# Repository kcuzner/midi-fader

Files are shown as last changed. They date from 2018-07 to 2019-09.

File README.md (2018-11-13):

# Simple MIDI Fader

By Kevin Cuzner

## Project Status

 * PCB complete and working (with an additional load added to reduce regulator noise)
 * Firmware feature-complete and mostly working
   * Emulates as HID and USB-MIDI devices
   * Not tested on Windows yet
 * Case OpenSCAD in progress
 * Configuration host software in progress

## Featureset

 * Two 60mm analog fader inputs
 * USB Audio Class interface, aiming for driverless on Windows 7 and 10
 * Driverless HID interface for configuration
   * It might be trivially simple to echo the fader status in the HID reports...

## Main Component Options

 * Faders (note that they have different footprints and different levers):
   * Expensive faders ($4.74, very light movement force): PTB6053-2010APB103-ND
   * Cheap faders ($1.73): PTA6043-2015CPB103-ND
 * Microcontrollers:
   * 497-17354-1-ND: STM32F070F6P6, $1.48, 32K flash, 6K RAM, 20-TSSOP.
     * No CRS, external XTAL required.
   * 497-15099-ND: STM32F070CBT6, $2.52, 128K flash, 16K RAM, 48-LQFP
     * No CRS, exteranl XTAL required.
   * 497-17344-ND: STM32042F6P6, $2.25, 32K flash, 6K RAM, 20-TSSOP.
     * Has a CRS
     * 24.6mA with all peripherals and HSI48 enabled
 * 609-4052-1-ND: Micro-USB, $0.76
 * 455-1790-1-ND: JST-SH header for programming, $0.63
 * Power supply solution:
   * MCP1603T-330I/OSCT-ND: Cheap buck regulator, but not too cheap. $1.01,
     TSOT-23
     * Noise issues at low currents (leaves PWM mode and skips pulses).
   * 576-4764-1-ND: MIC5504 buck regulator, $0.11, SOT23-5.
     * At a 100mA load, the case will heat 42.6C. Not over the top, but really
       quite hot.
     * We could do this AND the buck regulator, but just have this for the
       analog.

## Notes

### Notes about the logical MIDI protocol

 * MIDI has two types of bytes STATUS and DATA.
 * A STATUS byte has its MSB set
 * A DATA byte has its MSB cleared (hence why there are only ever 0 to 127 data
   values)
 * Usually, the lower nybble of the STATUS byte is a channel number (there are
   16 channels).
 * The number of data bytes to follow varies by which STATUS byte preceded them.
 * Interesting STATUS commands (upper nybble shown) for this project:
   * 0xB: Control Change. Followed by a controller number (1 data byte) and a
     controller value (1 data byte). Although there are possibly 127 controller
     numbers, numbers 120-127 are reserved for "Channel Mode Messages". Several
     of these are commonly used.
   * 0xE: Pitch Bend. Followed by two DATA bytes encoding a 14-bit value, LSB
     first. 0x2000 is center.
 * https://www.cs.cmu.edu/~music/cmsip/readings/MIDI%20tutorial%20for%20programmers.html
 * https://www.midi.org/specifications-old/item/table-1-summary-of-midi-message

### Notes about USB and MIDI

 * Windows XP and above seem to support USB MIDI except Elements.
   * "Elements" are things that process MIDI
   * "Jacks" are supported, and they are exactly what they sound like. This will
     implement a Jack.
   * Elements and Jacks are "Entities"
 * http://www.usb.org/developers/docs/devclass_docs/midi10.pdf

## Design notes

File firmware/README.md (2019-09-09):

# USB Midi-Fader Firmware

This is the firmware for the USB Midi-Fader. It runs on an STM32F042X6
microcontroller and has the following features:

- Enumerates as a USB Human Interface Device
- Enumerates as a USB Audio Device
- Reads up to 8 attached shift registers for button inputs
  - Detects how many shift registers are attached
- Writes up to 8 attached shift registers for LED outputs
- Reads up to 8 analog inputs
- Completely configurable in terms of what it sends
  - Emulates a Mackie control

## Building

### Build Prerequisites

These are names of Arch Linux packages.

- `arm-none-eabi-gcc`
- `arm-none-eabi-binutils`
- `arm-none-eabi-newlib`
- `python` (Python 3)
- `openocd`

### Build process

```
$ make
```

### Install process

This process will erase the device, flash the bootloader, then use a python
script to update the flash to contain the firmware binary.

```
$ make install
```

#### Installing the bootloader only

This erases the device and installs the bootloader, but stops short of
installing the firmware image. It does, however, require that the firmware can
be built since it uses the `storage` segment of the firmware.

```
$ make flash
```

### Update process

```
$ make update
```

### Debugging

```
$ make gdb
```

### Cleanup

An openocd server is started in the background whenever a flashing or debugging
operation is performed. To stop the server run:

```
$ make stop
```

This step is performed automatically when running `make clean`

## What can be configured

Generally:

- Event rate (`0x80000001`)

For each button:

- Channel (`0x4000NN01, NN = button number`)
- "On" value (`0x4000NN02`)
- "Off" value (`0x4000NN03`)
- Mode: Control or Note (`0x4000NN04`)
- Control number (`0x4000NN05`)
- Note number (`0x4000NN06`)

For each fader

- Channel (`0x2000NN01`, NN = fader number)
- Mode: Control or Pitch Bend (`0x2000NN02`)
- Control number (`0x2000NN03`)
- Control minimum (`0x2000NN04`)
- Control maximum (`0x2000NN05`)
- Pitch minimum (`0x2000NN06`)
- Pitch maximum (`0x2000NN07`)

Other read-only parameters:

- Number of faders/buttons: (`0x80000002`)

### Configuration Protocol

Configuration is accomplished through the HID interface, rather than directly
through MIDI (but maybe this will come later). The communication is arranged
through the two 64-byte IN and OUT reports.

In general, the reports have the following format:

```
Bytes 0-3: Command number
Bytes 4-7: Parameter 0
Bytes 8-11: Parameter 1
...
```

Words should be packed LSB first.

An IN report will contain the command number of the command it is responding to.
Parameters can be IN, OUT, or both. The parameters will be echoed in the
corresponding OUT report.

#### Status

The Status command has the following format:

 - Command: 0x00
 - Parameter 0 (IN): Constant 0xDEADBEEF
 - Parameter 1 (IN): Number of channels
 - Remaining parameters (IN): Null terminated git version string of the firmware

#### Set Parameter

The Set Parameter command has the following format:

 - Command: 0x80
 - Parameter 0 (IN): Status (0 = success, error code otherwise)
 - Parameter 1 (OUT): Parameter number
 - Parameter 2 (OUT): Parameter value
 - Parameter 3 (OUT): Parameter size in bytes

#### Get Parameter

The Get Parameter command has the following format:

 - Command: 0x40
 - Parameter 0 (IN): Status (0 = success, error code otherwise)
 - Parameter 1 (OUT): Parameter number
 - Parameter 2 (IN): Parameter value
 - Parameter 3 (IN): Parameter size in bytes

#### Enter Bootloader

The Enter Bootloader command has the following format:

 - Command: 0x0C
 - Parameters: Ignored

The device will immediately disconnect and re-enumerate as the bootloader device
upon receiving this command.

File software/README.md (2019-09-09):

# Software

The software for the midi fader is designed to be cross platform between Windows and Linux. With this in mind, it is
written in [Rust][1] and uses [imgui][2] for the user interface. There were many hiccups during development and it took
far far longer to write this than the entire PCB design and firmware development process. Most of this can be attributed
to my inexperience with Rust.

## Design Choices

### GUI

 - imgui is statically compiled into the application. This removes any dependency on external dynamically linked
   libraries.
 - Of the rather limited GUI options in Rust, I felt that imgui was the most developed since it mirrors the C API almost
   exactly.
 - The standard practice of having a special thread for GUI activity is followed, even though imgui is stateless.

### Device Communication

[1]: https://rust-lang.org
[2]: https://github.com/ocornut/imgui

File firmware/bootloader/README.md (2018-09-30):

# USB-Midi Fader Bootloader

The bootloader provides a mechanism for reprogramming the system without using
SWD beyond the first initial flashing of this image.

## Build instructions

**Prerequisites:**

 - arm-none-eabi-gcc
 - arm-none-eabi-binutils
 - python3

**To build:**

 1. Run `make` in this directory.

**To install or debug:**

Invoking `make` in this directory does not allow for actually flashing the
device. Since the application which uses this bootloader has its very own
"storage" segment, independent from the one generated here (which only contains
a very small subset of the parameters in storage), all flashing and debugging
should take place in the parent directory.

## Program Format

This bootloader lives in the first 8KB of program flash and reserves the first
256 bytes of RAM. Programs to be loaded through this bootloader must have their
sections located in the following format:

```
Flash:
0x08002000: User program (.text, .rodata, etc)

RAM:
0x20000100: User data until the end of memory

Information block:
All sections may be used by the program
```

All writes and reads to the bootloader section (0x08000000-0x08001FFF,
0x08080000-0x080800FF) will be ignored and generate an appropriate status
report.

Firmware which writes to the first 256 bytes of RAM may cause the bootloader
to behave unexpectedly.

## Programming Verification

The bootloader includes automatic program verification as the device is
programmed in half-pages. However, it is still recommended to read back the
entire user section of program memory to verify that all blocks have been
written.

As an additional countermeasure against incorrect programming, once the device
enters bootloader mode, it will always enter bootloader mode on reset until
the "Exit Bootloader Mode" command is received. This prevents errors stemming
from device resets or loss of power during the programming process by allowing
the host software to start over programming without needing to resort to an
external reset.

## Protocol

### Entering Bootloader Mode

Bootloader is entered by simply performing any reset except a power-on reset.
If the power-on reset bit is set, the bootloader clears it and then jumps to the
user program, if it has been programmed.

### USB

The bootloader will appear as a USB device using the shared libusb VID/PID and
the name "LED Wristwatch Bootloader". It enumerates as an HID device and will
send and receive 64-byte reports. Each report encapsulates a command. As the
device is stateful, multiple host programs accessing the device at once may
cause corruption. The IN and OUT reports both utilize the default HID report ID,
so no HID report ID needs to be sent with the report.

The device will generate 64-byte IN reports on occasion to communicate the
device status. These reports have the following format:

```
Byte 0-3: First four bytes of the last command received or 0x00000000
Byte 4-7: Status flags
Byte 8-11: CRC32 of the lower page report to follow or just processed, if applicable
Byte 12-15: CRC32 of the upper page report to follow or just processed, if applicable
Byte 16-63: N/A
```

For an interpretation of the status flags, please see the `BootloaderError` enum
defined in `src/bootloader.c`. In general, these flags will only be set on
error and a `0` in the flags value can be interpreted as command success.

### CRC32 Implementation

The CRC32 is implemented using the hardware on the STM32. The host software will
use the `zlib` implementation of CRC32.

### Resetting the programming state machine

When the host program starts, a state machine reset command should be sent to
ensure the device is in a known state before performing any programming
commands. The reset command consists of sending the following report three
times:

The reset command has the following format:

```
Byte 0-63: 0x00
```

Upon receipt of the command, the device will generate a status report

### Exiting Bootloader Mode Before Programming

If the bootloader was started, but no programming operations have occurred and
the device was previously programmed, the user program can be started by issuing
the following command:

```
Byte 0: 0x3E
Byte 1-3: 0x00
Byte 4-63: N/A
```

Upon receipt of this command, the device will immediately reset and enter the
user program, if one has already been programmed and no new programming commands
have been received. Otherwise, a status report will be generated with an
appropriate error flag.

### Erasing the Flash

The STM32F0xx erases by 1KB page. Prior to programming the flash, an erase
command should be sent for each page:

```
Byte 0: 0x88
Byte 1-3: 0x00
Byte 4: Destination address bits 7-0 (bits 6-0 are ignored)
Byte 5: Destination address bits 15-8
Byte 6: Destination address bits 23-16
Byte 7: Destination address bits 31-24
Byte 8-63: N/A
```

Upon receipt of this command, the device will erase the 1KB page that the passed
address lies within and issue a status report.

### Programming the Flash

Programming the flash requires 3 reports to be sent: A write command and
two half-page OUT reports.

The write command has the following format:

```
Byte 0: 0x80
Byte 1-3: 0x00
Byte 4: Destination address bits 7-0 (bits 6-0 are ignored)
Byte 5: Destination address bits 15-8
Byte 6: Destination address bits 23-16
Byte 7: Destination address bits 31-24
Byte 8-11: CRC32 of the 16 32-bit words from the lower page command to follow, LSB first
Byte 12-15: CRC32 of the 16 32-bit words from the upper page command to follow, LSB first
Byte 16-63: N/A
```

Upon receipt of this command, the device will enter programming mode verify the
address that is to be written along with the erase state. The page must have
been previously erased.

The half-page command has the following format:

```
Byte 0-63: 16 32-bit words to program
```

Upon receipt of this command, the device will proceed to program the 16 words
starting at the destination address. In the event that less than a page needs
to be written, the remaining bytes should be filled with 0x00. When programming
has been completed, a status report will be generated and the device is ready to
receive the next page. Upon receipt of the final, upper page command, another
status report is generated and the device returns to the reset state.

Status commands during the programming phase will contain either a valid CRC32
for any section programmed, or zeros if the section has not been programmed. If
any error flags are set, then the device has returned to the reset state.

### Reading the Flash

Reading the flash requires 1 report to be sent and another to be received:
A read command and the page IN report.

The read command has the following format:

```
Byte 0: 0x40
Byte 1-3: 0x00
Byte 4: Source address bits 7-0 (bits 6-0 are ignored)
Byte 5: Source address bits 15-8
Byte 6: Source address bits 23-16
Byte 7: Source address bits 31-24
Byte 8-63: N/A
```

Upon receipt of this command, the device will generate two IN reports containing
the contents of the page. A status report will immediately follow and the device
returns to the reset state, being ready to accept the next command.

### Exiting Bootloader Mode After Programming

To exit bootloader mode, a report with the following format should be sent:

```
Byte 0: 0xC3
Byte 1-3: 0x00
Byte 4-7: VTOR value for the user program
Byte 8-63: N/A
```

The VTOR value should be the address at which the user program's interrupt
vector table resides. The first two words of the table are used to derive the
initial stack pointer and the location to jump to in order to initiate the user
program (reset vector).

Upon receipt of this command, the device will write the VTOR value to persistent
EEPROM and reset the device. If the VTOR value passed is invalid, or the device
is unable to write its EEPROM, it will send a status report detailing the
failure. Otherwise, it will initiate a device soft reset and the user program
will start on every power-on or low-power reset thereafter.

**This command must not be sent until the entire program has been written to
the flash.** In the event that the device stops programming before receiving
this command, it will automatically enter bootloader mode at the next reset
until it receives this command.

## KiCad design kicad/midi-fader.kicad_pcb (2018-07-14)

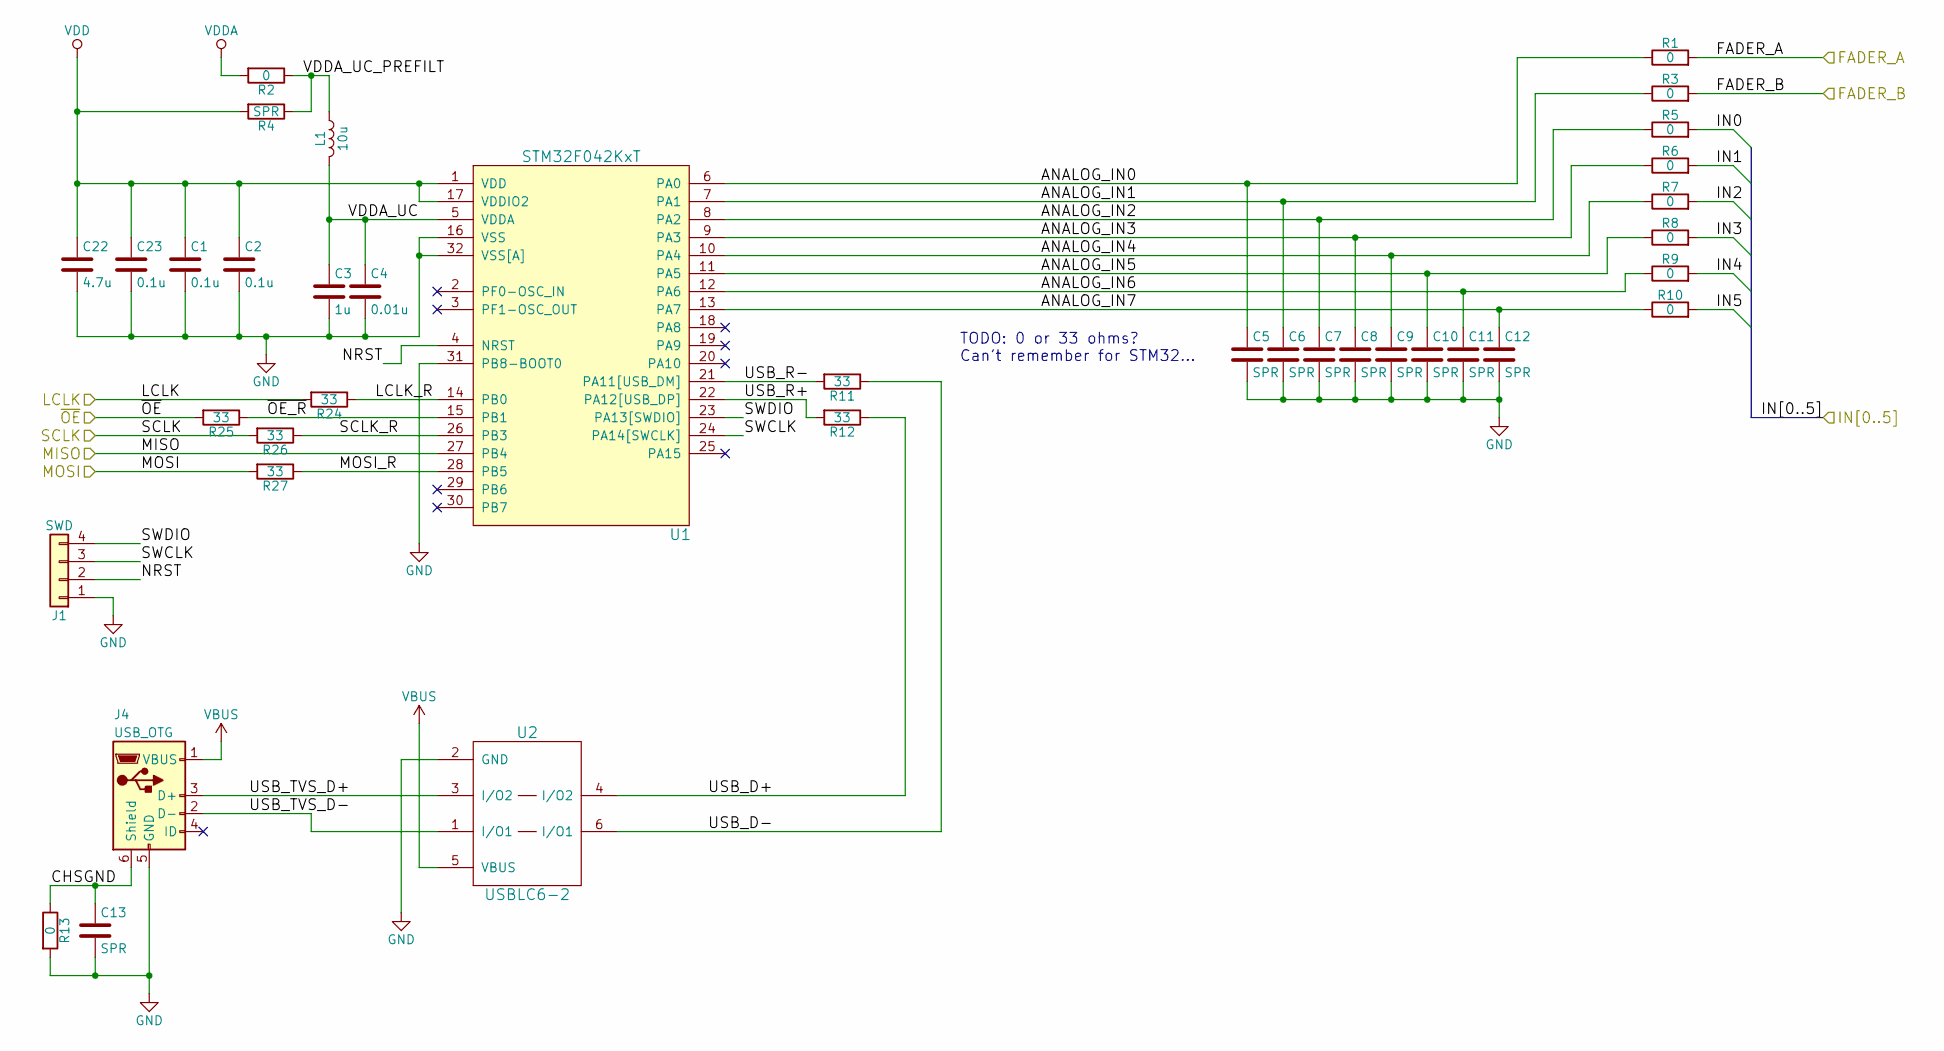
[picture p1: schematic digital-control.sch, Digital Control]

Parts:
C1, C2, C23: 0.1u; C_0402; Part No. 1276-1043-1-ND
C3: 1u; C_0603; Part No. 1276-1182-1-ND
C4: 0.01u; C_0402; Part No. 399-1038-1-ND
C5, C6, C7, C8, C9, C10, C11, C12, C13: SPR; C_0402
C22: 4.7u; C_0805; Part No. 1276-6464-1-ND
J1: SWD; JST-SH-4; Part No. 455-1790-1-ND
J4: USB_OTG; AMP-10104110-USB; Part No. 609-4052-1-ND
L1: 10u; R_0805; Part No. 587-2045-1-ND
R1, R2, R3, R5, R6, R7, R8, R9, R10, R13: 0; R_0402
R4: SPR; R_0402
R11, R12, R24, R25, R26, R27: 33; R_0402
U1: STM32F042KxT; LQFP-32_7x7mm_Pitch0.8mm; Part No. 497-14647-ND
U2: USBLC6-2; SOT-666; Part No. 497-5026-1-ND

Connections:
/Digital Control/ANALOG_IN0: C5.1, R1.1, U1.6 (PA0)
/Digital Control/ANALOG_IN1: C6.1, R3.1, U1.7 (PA1)
/Digital Control/ANALOG_IN2: C7.1, R5.1, U1.8 (PA2)
/Digital Control/ANALOG_IN3: C8.1, R6.1, U1.9 (PA3)
/Digital Control/ANALOG_IN4: C9.1, R7.1, U1.10 (PA4)
/Digital Control/ANALOG_IN5: C10.1, R8.1, U1.11 (PA5)
/Digital Control/ANALOG_IN6: C11.1, R9.1, U1.12 (PA6)
/Digital Control/ANALOG_IN7: C12.1, R10.1, U1.13 (PA7)
/Digital Control/CHSGND: C13.1, J4.6 (Shield), R13.1
/Digital Control/FADER_A: R1.2; also elsewhere on the board
/Digital Control/FADER_B: R3.2; also elsewhere on the board
/Digital Control/IN0: R5.2; also elsewhere on the board
/Digital Control/IN1: R6.2; also elsewhere on the board
/Digital Control/IN2: R7.2; also elsewhere on the board
/Digital Control/IN3: R8.2; also elsewhere on the board
/Digital Control/IN4: R9.2; also elsewhere on the board
/Digital Control/IN5: R10.2; also elsewhere on the board
/Digital Control/LCLK: R24.2; also elsewhere on the board
/Digital Control/LCLK_R: R24.1, U1.14 (PB0)
/Digital Control/MISO: U1.27 (PB4); also elsewhere on the board
/Digital Control/MOSI: R27.2; also elsewhere on the board
/Digital Control/MOSI_R: R27.1, U1.28 (PB5)
/Digital Control/NRST: J1.2, U1.4 (NRST)
/Digital Control/SCLK: R26.2; also elsewhere on the board
/Digital Control/SCLK_R: R26.1, U1.26 (PB3)
/Digital Control/SWCLK: J1.3, U1.24 (PA14[SWCLK])
/Digital Control/SWDIO: J1.4, U1.23 (PA13[SWDIO])
/Digital Control/USB_D+: R12.1, U2.4 (I/O2)
/Digital Control/USB_D-: R11.1, U2.6 (I/O1)
/Digital Control/USB_R+: R12.2, U1.22 (PA12[USB_DP])
/Digital Control/USB_R-: R11.2, U1.21 (PA11[USB_DM])
/Digital Control/USB_TVS_D+: J4.3 (D+), U2.3 (I/O2)
/Digital Control/USB_TVS_D-: J4.2 (D-), U2.1 (I/O1)
/Digital Control/VDDA_UC: C3.1, C4.1, L1.2, U1.5 (VDDA)
/Digital Control/VDDA_UC_PREFILT: L1.1, R2.1, R4.1
/Digital Control/~OE: R25.2; also elsewhere on the board
/Digital Control/~OE_R: R25.1, U1.15 (PB1)
GND: C1.2, C2.2, C3.2, C4.2, C5.2, C6.2, C7.2, C8.2, C9.2, C10.2, C11.2, C12.2, C13.2, C22.2, C23.2, J1.1, J4.5 (GND), R13.2, U1.16 (VSS), U1.31 (PB8-BOOT0), U1.32 (VSS[A]), U2.2 (GND); also elsewhere on the board
VBUS: J4.1 (VBUS), U2.5 (VBUS); also elsewhere on the board
VDD: C1.1, C2.1, C22.1, C23.1, R4.2, U1.1 (VDD), U1.17 (VDDIO2); also elsewhere on the board
VDDA: R2.2; also elsewhere on the board

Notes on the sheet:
TODO: 0 or 33 ohms? Can't remember for STM32...

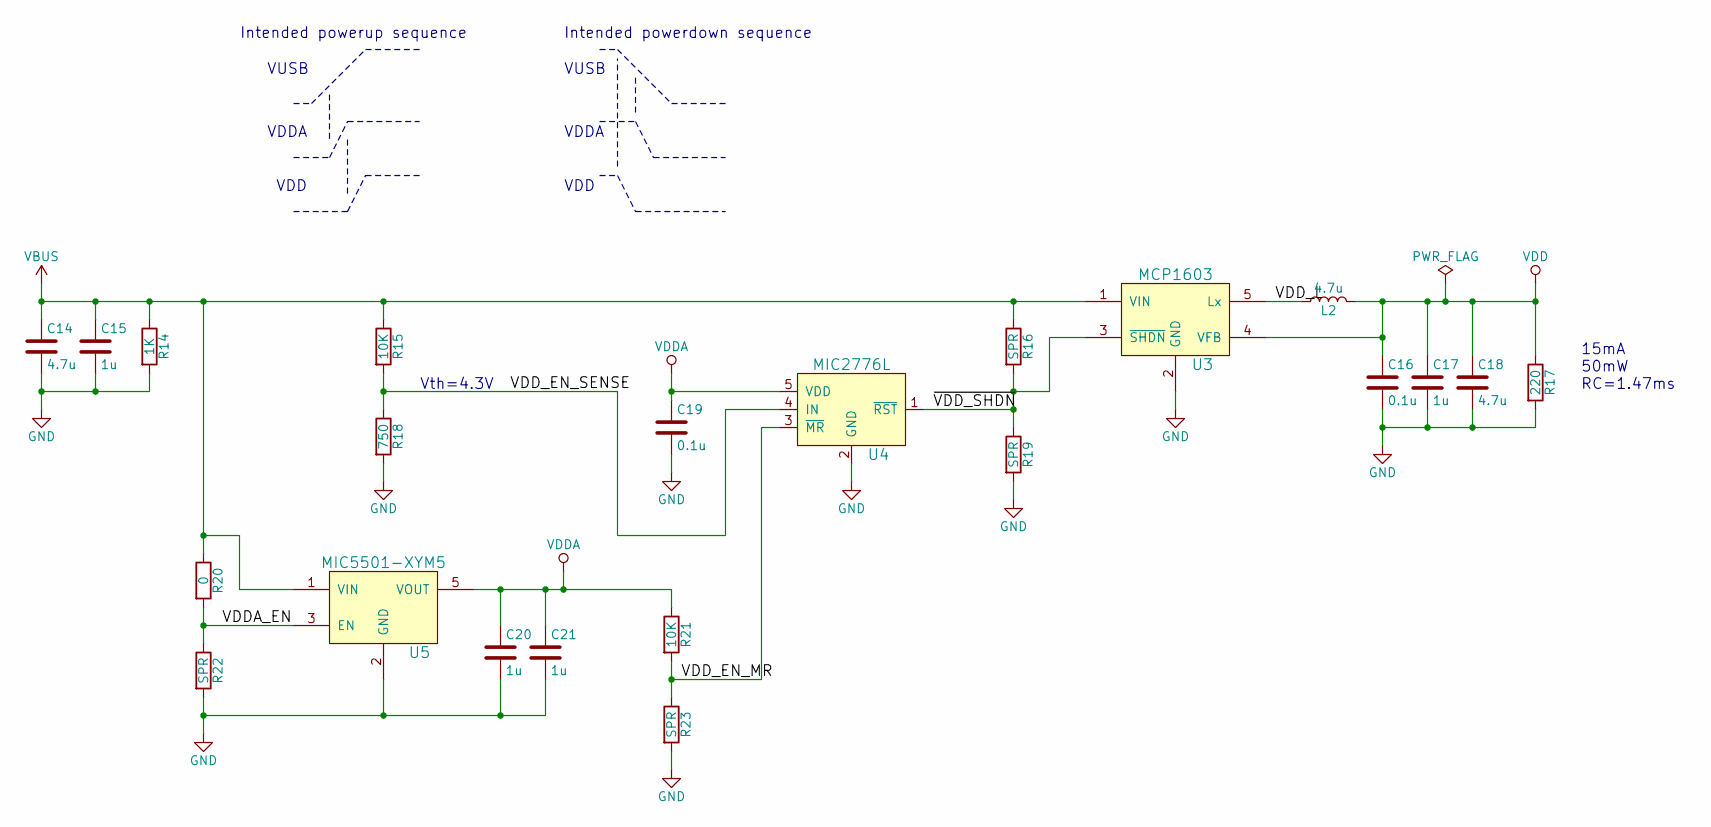
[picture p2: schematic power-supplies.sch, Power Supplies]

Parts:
C14, C18: 4.7u; C_0805; Part No. 1276-6464-1-ND
C15, C17, C20, C21: 1u; C_0603; Part No. 1276-1182-1-ND
C16, C19: 0.1u; C_0402; Part No. 1276-1043-1-ND
L2: 4.7u; Wurth_TPC_3816; Part No. 732-1008-1-ND
R14: 1K; R_0805
R15, R21: 10K; R_0402
R16, R19, R22, R23: SPR; R_0402
R17: 220; R_1206
R18: 750; R_0402
R20: 0; R_0402
U3: MCP1603; TSOT-23-5; Part No. MCP1603T-330I/OSCT-ND
U4: MIC2776L; SOT-23-5; Part No. 576-2686-1-ND
U5: MIC5501-XYM5; SOT-23-5; Part No. 576-4764-1-ND

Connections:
/Power Supplies/VDDA_EN: R20.2, R22.1, U5.3 (EN)
/Power Supplies/VDD_EN_MR: R21.2, R23.1, U4.3 (~MR)
/Power Supplies/VDD_EN_SENSE: R15.2, R18.1, U4.4 (IN)
/Power Supplies/VDD_L: L2.1, U3.5 (Lx)
/Power Supplies/~VDD_SHDN: R16.2, R19.1, U3.3 (~SHDN), U4.1 (~RST)
GND: C14.2, C15.2, C16.2, C17.2, C18.2, C19.2, C20.2, C21.2, R14.2, R17.2, R18.2, R19.2, R22.2, R23.2, U3.2 (GND), U4.2 (GND), U5.2 (GND); also elsewhere on the board
VBUS: C14.1, C15.1, R14.1, R15.1, R16.1, R20.1, U3.1 (VIN), U5.1 (VIN); also elsewhere on the board
VDD: C16.1, C17.1, C18.1, L2.2, R17.1, U3.4 (VFB); also elsewhere on the board
VDDA: C19.1, C20.1, C21.1, R21.1, U4.5 (VDD), U5.5 (VOUT); also elsewhere on the board

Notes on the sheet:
Intended powerup sequence
VUSB
VDDA
VDD
Intended powerdown sequence
15mA 50mW RC=1.47ms
Vth=4.3V

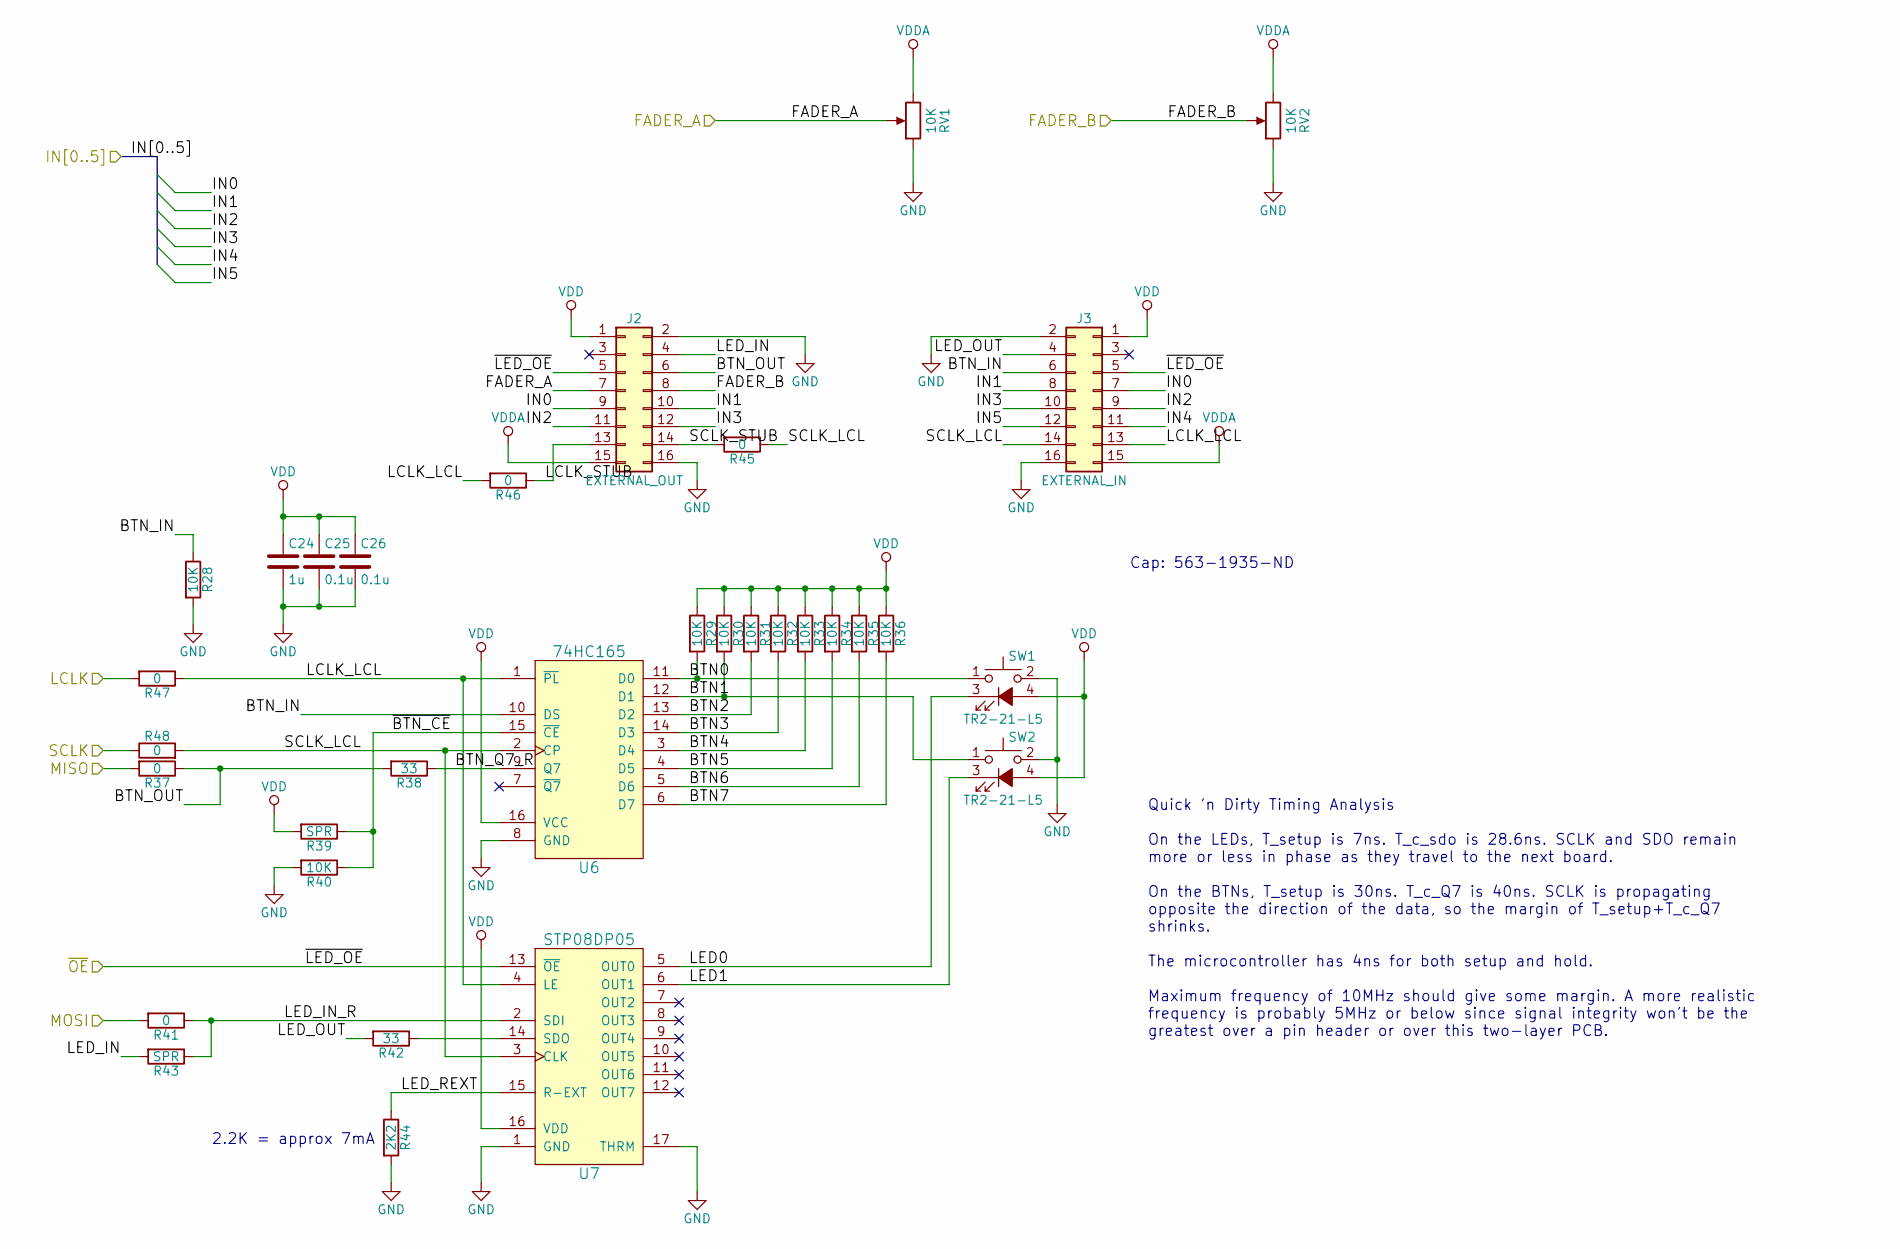
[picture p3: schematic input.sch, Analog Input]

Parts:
C24: 1u; C_0603; Part No. 1276-1182-1-ND
C25, C26: 0.1u; C_0402; Part No. 1276-1043-1-ND
J2: EXTERNAL_OUT; Pin_Header_Angled_2x08_Pitch2.54mm; Part No. 609-3346-ND
J3: EXTERNAL_IN; Socket_Strip_Angled_2x08_Pitch2.54mm; Part No. S5561-ND
R28, R29, R30, R31, R32, R33, R34, R35, R36, R40: 10K; R_0402
R37, R41, R45, R46, R47, R48: 0; R_0402
R38, R42: 33; R_0402
R39, R43: SPR; R_0402
R44: 2K2; R_0402
RV1, RV2: 10K; BOURNS_PTA60X3; Part No. PTA6043-2015CPB103-ND
SW1, SW2: TR2-21-L5; Nidec_Copal_TR2; Part No. 563-1933-ND
U6: 74HC165; TSSOP-16_4.4x5mm_Pitch0.65mm; Part No. 1727-4295-1-ND
U7: STP08DP05; HTSSOP-16-1EP_4.4x5mm_Pitch0.65mm_ThermalVias_HandSolder; Part No. 497-6119-1-ND

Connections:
/Digital Control/FADER_A: J2.7, RV1.2; also elsewhere on the board
/Digital Control/FADER_B: J2.8, RV2.2; also elsewhere on the board
/Digital Control/IN0: J2.9, J3.7; also elsewhere on the board
/Digital Control/IN1: J2.10, J3.8; also elsewhere on the board
/Digital Control/IN2: J2.11, J3.9; also elsewhere on the board
/Digital Control/IN3: J2.12, J3.10; also elsewhere on the board
/Digital Control/IN4: J3.11; also elsewhere on the board
/Digital Control/IN5: J3.12; also elsewhere on the board
/Digital Control/LCLK: R47.2; also elsewhere on the board
/Digital Control/MISO: R37.2; also elsewhere on the board
/Digital Control/MOSI: R41.2; also elsewhere on the board
/Digital Control/SCLK: R48.1; also elsewhere on the board
/Digital Control/~OE: J2.5, J3.5, U7.13 (~OE); also elsewhere on the board
/Input/BTN0: R29.2, SW1.1, U6.11 (D0)
/Input/BTN1: R30.2, SW2.1, U6.12 (D1)
/Input/BTN2: R31.2, U6.13 (D2)
/Input/BTN3: R32.2, U6.14 (D3)
/Input/BTN4: R33.2, U6.3 (D4)
/Input/BTN5: R34.2, U6.4 (D5)
/Input/BTN6: R35.2, U6.5 (D6)
/Input/BTN7: R36.2, U6.6 (D7)
/Input/BTN_IN: J3.6, R28.1, U6.10 (DS)
/Input/BTN_OUT: J2.6, R37.1, R38.2
/Input/BTN_Q7_R: R38.1, U6.9 (Q7)
/Input/LCLK_LCL: J3.13, R46.2, R47.1, U6.1 (~PL), U7.4 (LE)
/Input/LCLK_STUB: J2.13, R46.1
/Input/LED0: SW1.3 (K), U7.5 (OUT0)
/Input/LED1: SW2.3 (K), U7.6 (OUT1)
/Input/LED_IN: J2.4, R43.2
/Input/LED_IN_R: R41.1, R43.1, U7.2 (SDI)
/Input/LED_OUT: J3.4, R42.2
/Input/LED_REXT: R44.1, U7.15 (R-EXT)
/Input/SCLK_LCL: J3.14, R45.1, R48.2, U6.2 (CP), U7.3 (CLK)
/Input/SCLK_STUB: J2.14, R45.2
/Input/~BTN_CE: R39.1, R40.1, U6.15 (~CE)
GND: C24.2, C25.2, C26.2, J2.2, J2.16, J3.2, J3.16, R28.2, R40.2, R44.2, RV1.1, RV2.1, SW1.2, SW2.2, U6.8 (GND), U7.1 (GND), U7.17 (THRM); also elsewhere on the board
unnamed: R42.1, U7.14 (SDO)
VDD: C24.1, C25.1, C26.1, J2.1, J3.1, R29.1, R30.1, R31.1, R32.1, R33.1, R34.1, R35.1, R36.1, R39.2, SW1.4 (A), SW2.4 (A), U6.16 (VCC), U7.16 (VDD); also elsewhere on the board
VDDA: J2.15, J3.15, RV1.3, RV2.3; also elsewhere on the board

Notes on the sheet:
2.2K = approx 7mA
Quick 'n Dirty Timing Analysis On the LEDs, T_setup is 7ns. T_c_sdo is 28.6ns. SCLK and SDO remain more or less in phase as they travel to the next board. On the BTNs, T_setup is 30ns. T_c_Q7 is 40ns. SCLK is propagating opposite the direction of the data, so the margin of T_setup+T_c_Q7 shrinks. T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
Cap: 563-1935-ND

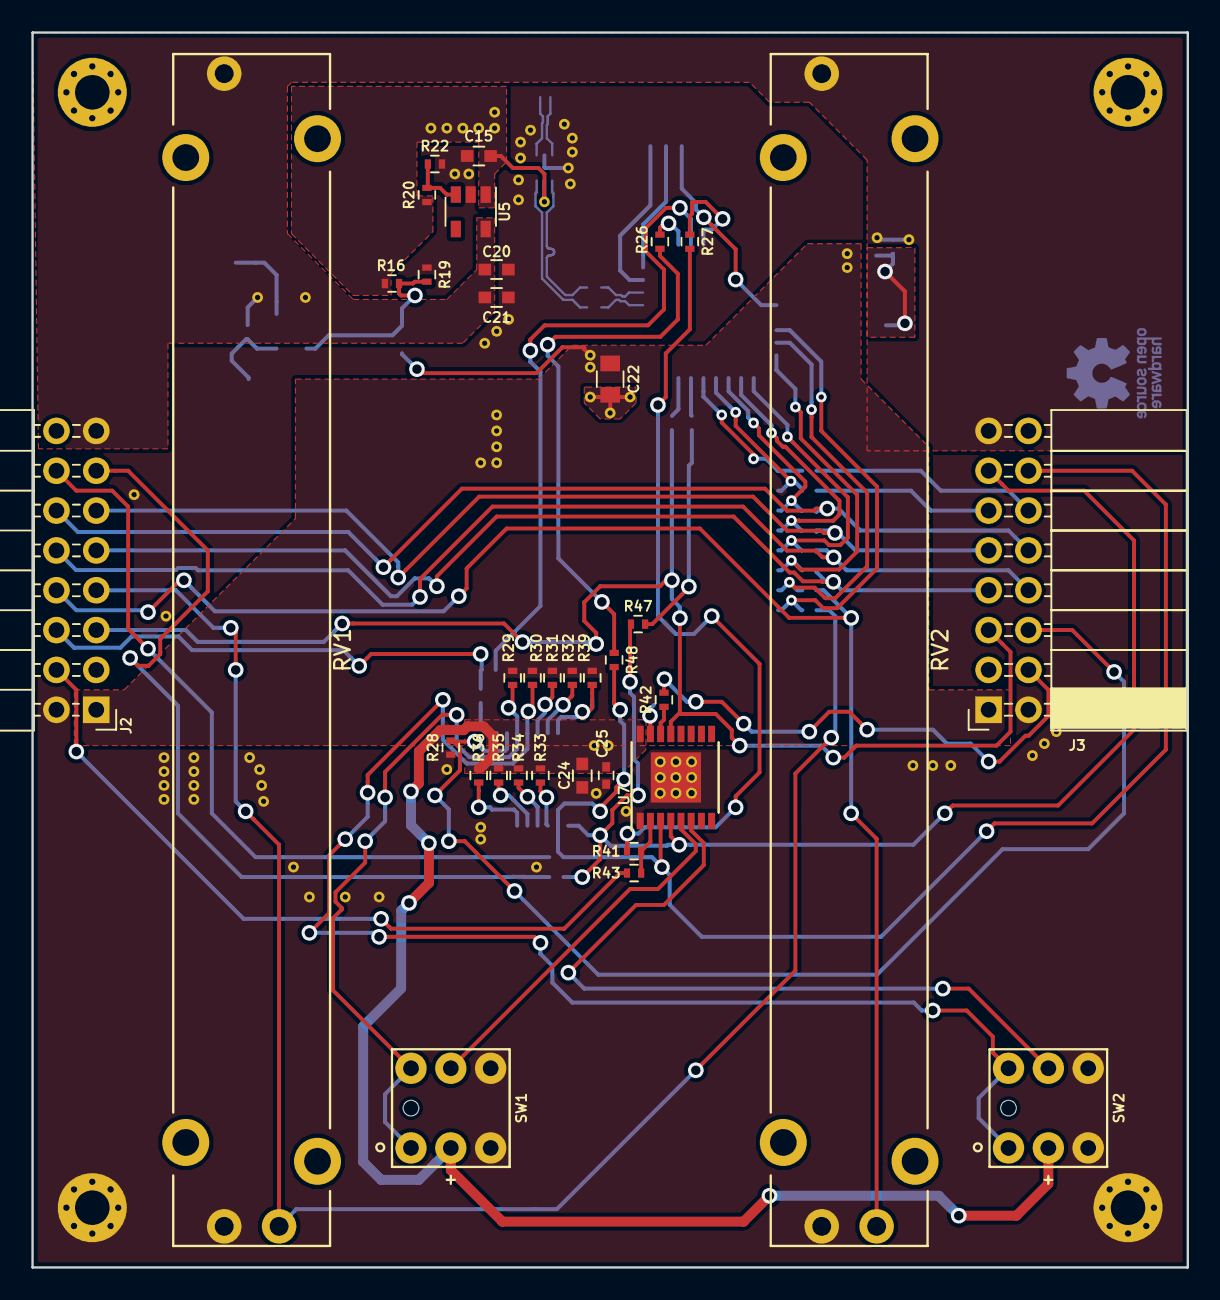
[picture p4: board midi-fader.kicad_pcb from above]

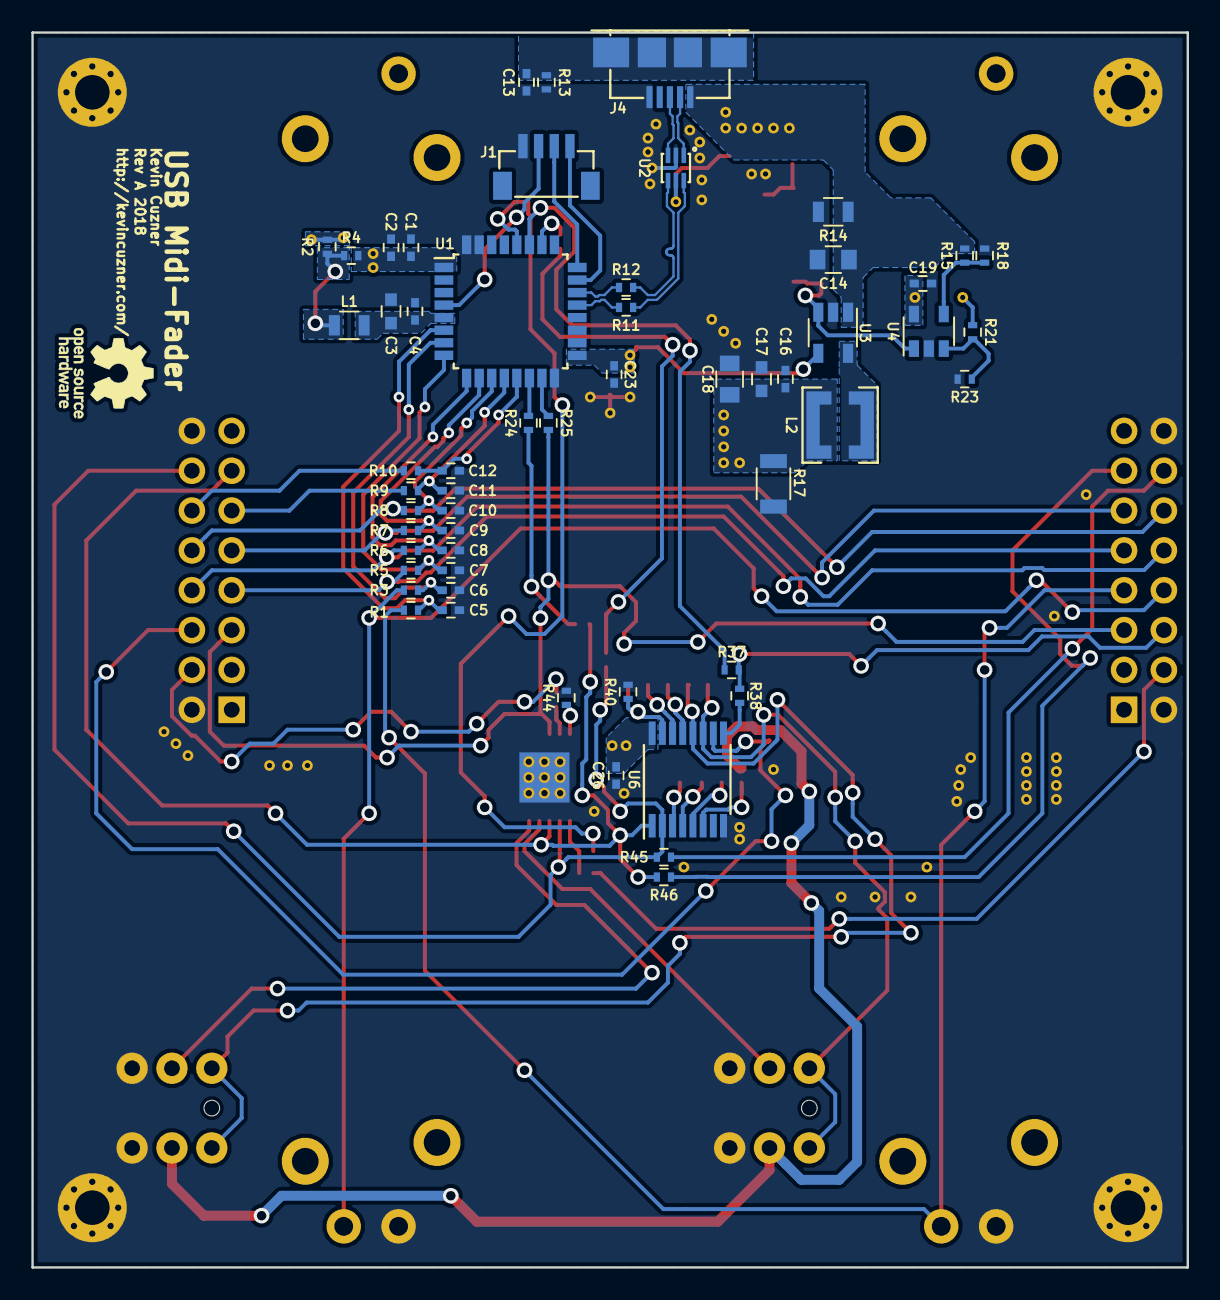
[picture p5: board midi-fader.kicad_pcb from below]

Board: 2 copper layers, 73.7 x 78.7 mm, 91 parts (56 on the bottom side), 69 nets.

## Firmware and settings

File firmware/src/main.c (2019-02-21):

/**
 * USB Midi-Fader
 *
 * Kevin Cuzner
 *
 * Main Application
 */

#include "usb.h"
#include "usb_app.h"
#include "usb_hid.h"
#include "usb_midi.h"
#include "osc.h"
#include "error.h"
#include "storage.h"
#include "fader.h"
#include "buttons.h"
#include "systick.h"
#include "mackie.h"

#include "stm32f0xx.h"

#include "_gen_usb_desc.h"

/**
 * <descriptor id="device" type="0x01">
 *  <length name="bLength" size="1" />
 *  <type name="bDescriptorType" size="1" />
 *  <word name="bcdUSB">0x0110</word>
 *  <byte name="bDeviceClass">0</byte>
 *  <byte name="bDeviceSubClass">0</byte>
 *  <byte name="bDeviceProtocol">0</byte>
 *  <byte name="bMaxPacketSize0">USB_CONTROL_ENDPOINT_SIZE</byte>
 *  <word name="idVendor">0x16c0</word>
 *  <word name="idProduct">0x05dc</word>
 *  <word name="bcdDevice">0x0010</word>
 *  <ref name="iManufacturer" type="0x03" refid="manufacturer" size="1" />
 *  <ref name="iProduct" type="0x03" refid="product" size="1" />
 *  <byte name="iSerialNumber">0</byte>
 *  <count name="bNumConfigurations" type="0x02" size="1" />
 * </descriptor>
 * <descriptor id="lang" type="0x03" first="first">
 *  <length name="bLength" size="1" />
 *  <type name="bDescriptorType" size="1" />
 *  <foreach type="0x03" unique="unique">
 *    <echo name="wLang" />
 *  </foreach>
 * </descriptor>
 * <descriptor id="manufacturer" type="0x03" wIndex="0x0409">
 *  <property name="wLang" size="2">0x0409</property>
 *  <length name="bLength" size="1" />
 *  <type name="bDescriptorType" size="1" />
 *  <string name="wString">kevincuzner.com</string>
 * </descriptor>
 * <descriptor id="product" type="0x03" wIndex="0x0409">
 *  <property name="wLang" size="2">0x0409</property>
 *  <length name="bLength" size="1" />
 *  <type name="bDescriptorType" size="1" />
 *  <string name="wString">Midi-Fader</string>
 * </descriptor>
 * <descriptor id="configuration" type="0x02">
 *  <length name="bLength" size="1" />
 *  <type name="bDescriptorType" size="1" />
 *  <length name="wTotalLength" size="2" all="all" />
 *  <count name="bNumInterfaces" type="0x04" associated="associated" size="1" />
 *  <byte name="bConfigurationValue">1</byte>
 *  <byte name="iConfiguration">0</byte>
 *  <byte name="bmAttributes">0x80</byte>
 *  <byte name="bMaxPower">250</byte>
 *  <children type="0x04" />
 * </descriptor>
 */

#include <stddef.h>

static const USBInterfaceListNode midi_interface_node = {
    .interface = &midi_interface,
    .next = NULL,
};

static const USBInterfaceListNode hid_interface_node = {
    .interface = &hid_interface,
    .next = &midi_interface_node,
};

const USBApplicationSetup setup = {
    .interface_list = &hid_interface_node,
};

const USBApplicationSetup *usb_app_setup = &setup;

static volatile uint32_t tick_count = 0;
static void update_tick(void)
{
    tick_count++;
}

uint8_t buf[16];
int main()
{
    osc_request_hsi8();

    systick_init();

    __enable_irq();

    usb_init();
    fader_init();
    buttons_init();
    mackie_init();


    // Small delay to force a USB reset
    usb_disable();
    tick_count = 0;
    systick_subscribe(&update_tick);
    while (tick_count < 20) { } //at least 10ms needed, so we do 20ms
    usb_enable();

    while (1)
    {
        mackie_tick();
    }

    return 0;
}

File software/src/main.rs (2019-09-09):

//! Host software GUI for the midi-fader

#![recursion_limit="128"]

extern crate arrayvec;
extern crate byteorder;
extern crate errno;
#[macro_use]
extern crate failure;
#[macro_use]
extern crate futures;
extern crate glium;
extern crate imgui;
extern crate imgui_glium_renderer;
extern crate imgui_winit_support;
extern crate libc;
extern crate mio;
#[macro_use]
extern crate paste;
extern crate tokio;

#[cfg(target_os="linux")]
extern crate udev;

#[cfg(target_os="windows")]
extern crate winapi;

mod device;
mod config;
mod gui;

use std::thread;
use tokio::prelude::*;
use device::{Device, MidiFaderExtensions};

fn main() {
    let (requests_tx, requests_rx) = tokio::sync::mpsc::channel(10usize);

    let handle = thread::spawn(move || {
        let configurator = config::configure(requests_rx)
            .map_err(|e| panic!("Configuration failed. {}", e));
        tokio::run(configurator);
    });

    gui::gui_main(requests_tx);
    handle.join().unwrap();
}

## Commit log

2018-07-05 Finished initial part selection, built footprints
    I'm not sure about my footprint selection for the expansion headers,
    even though it is just a 0.1" header I want to be fairly exact about the
    length the pins stick out and how close the female header is to the
    edge, so that I can get a good distance between the two boards.
    [digital-control.sch, midi-fader.sch, power-supplies.sch]
2018-07-05 Added 3D models and made initial sizing placement
    I haven't compensated for the thickness of the case walls yet so that
    may need some adjustment. The objective is to have the sliders all
    equidistant when they are plugged in a row.
    [midi-fader.kicad_pcb]
2018-07-05 Changed microcontroller to 32-LQFP variety
    [digital-control.sch, midi-fader.kicad_pcb]
2018-07-05 Completed initial placement
    [digital-control.sch, midi-fader.kicad_pcb, power-supplies.sch]
2018-07-06 Initial routing complete
    [digital-control.sch, midi-fader.kicad_pcb]
2018-07-06 Added corner grounded mounting holes
    At the moment I plan on actually attaching the cover using the M2 screw
    holes on the sliders themselves, but this seems like a good backup
    option to have.
    [midi-fader.kicad_pcb]
2018-07-07 Restructured schematic to have a separate input page
    [digital-control.sch, input.sch, midi-fader.kicad_pcb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]
2018-07-08 Created shift register circuitry and imported footprints
    I think 5MHz to 10MHz is the theoretical maximum of this circuit. Actual
    frequency will probably be around 5MHz or somewhat less given the signal
    integrity issues on a 2-layer board with this many plane breaks.
    Created footprints for button and HTSSOP
    The HTSSOP footprint is special because I plan to hand solder, so I
    added excessive thermal vias and a bare pad on the backside.
    The netlist is imported to the PCB, but only the switches are placed.
    [digital-control.sch, input.sch, midi-fader.kicad_pcb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]
2018-07-13 Layout completed, first pass
    [midi-fader.kicad_pcb]
2018-07-13 Marked no-connects and changed some plane shapes
    [digital-control.sch, midi-fader.kicad_pcb]
2018-07-14 Added stub-removal resistors on clock lines, started cleaning silkscreen
    [digital-control.sch, input.sch, midi-fader.kicad_pcb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]
2018-07-14 Finished refdes tweaks, added OSHW logo and license
    [midi-fader.kicad_pcb]
2018-07-14 Moved sense location of VDD
    [midi-fader.kicad_pcb]
2018-07-14 Applied date and title to all schematic pages and PCB
    [digital-control.sch, input.sch, midi-fader.kicad_pcb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]
2018-07-14 Fixed NPTH on the sliders
    Those are not supposed to be non-plated. Whoops.
    [midi-fader.kicad_pcb]
2018-07-14 Adding Rev A gerbers
    [midi-fader-B.Cu.gbr, midi-fader-B.Mask.gbr, midi-fader-B.SilkS.gbr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]
2018-07-25 Added openocd helpers
    [flash.cfg]
2018-07-26 Added device USB driver and HID implementation from simple-led-watch
    Some modification was necessary because of the way the HSI48 is
    implemented on the STM32F042, but mostly it is the same.
    One oddity is that when the device is first programmed, linux can't
    find the interrupt endpoint. After a device reset or when the device is
    plugged back in anew it can find the interrupt endpoint.
    [main.c]
2018-08-01 Started on the usb generator script, creating a basic framework
    I feel like this is too specific, so I'm going to attempt to abstract
    descriptors generally so that I don't have to ever modify this script to
    add new descriptor types. All the work should be in the XML itself.
2018-08-11 Replaced descriptors with generated ones
    [main.c]
2018-08-19 Added initial USB MIDI interface descriptor and scaffold
    I'm not 100% sure the descriptor is working, since I get lots of errors
    when I open ardour. However, ardour does show it as a midi device. In
    addition, I think I need to revisit address assignment in the
    descriptorgen, since the usb_endpoint_setup actually takes the endpoint
    number separate from the address (not sure why I didn't notice this
    before).
    [main.c]
2018-08-19 Fixed issues with endpoint assignment and status
    The descriptorgen needed to be changed so that it talks in terms of
    endpoint numbers, not addresses.
    The usb_endpoint_setup method also had an issue where it would keep
    endpoints disabled, even though they were set up. Those endpoints now
    NAK instead, which I believe is the correct behavior. At least now
    ardour doesn't flood my log with -32 errors when it tries to read the
    device.
    [main.c]
2018-08-21 Added initial sending of an event
    It fails after the 3rd buffer is filled. The processor hard faults.
    [main.c]
2018-08-22 Simplified buffer to resolve the hard fault, fixed reset issue
    The device gets occasional resets, but the midi interface did not reset
    its internal buffer. It will now reset its buffer every time it is
    (re)configured.
    [main.c]
2018-08-23 Fixed MIDI, finally sent a valid control change event
    [main.c]
2018-08-25 Added initial storage section and generator at end of flash
    The XML file contains the configuration and the python script generates
    the appropriate structures. The linker script reserves a section of the
    flash for this special storage.
    [configuration.h]
2018-08-29 Added initial HID host interface for parameter get/set
    There is a problem with the set. Our first error!
    [configuration.h]
2018-08-31 Fixed storage and configuration implementation, added verbose errors
    There were many tiny bugs with the storage implementation, especially
    with writing and migration. Enough of them are fixed that I can now
    write a value 512 times (which migrates at least twice) and have no
    issues.
    Yeah error is a bad name...
    [main.c]
2018-09-06 Upgraded schematic to Kicad 5
    [digital-control.sch, input.sch, midi-fader.sch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]
2018-09-06 Added sequenced conversion for all fader channels
    The DMA is used to continuously transfer the conversion data.
2018-09-08 Added initial DMA-driven shift registers
    There is a big problem: I made a mistake with LE and PL#. Apparently
    when PL# is low, the shift register always outputs high. However,
    whenever LE is high it will continually load the LEDs, so the user would
    see weird LED patterns.
    I think I can work around this by briefly turning off the LEDs. The
    transactions take like 20us to complete.
    Another issue is the fact that for some reason we are transferred 64
    bits instead of 32.
    [buttons.c, main.c]
2018-09-08 Fixed bad wiring with a bad workaround
    I drastically lowered how often we query the shift registers, but kept
    them going as fast as possible. OE# is deasserted for the duration of
    the transmission and PL#/LE is brought high so that the input register
    actually gives us real data (side effect: the LED shift register is
    outputting everything it sees on its serial input, hence why we
    deasserted OE#). At the conclusion of the transmission, OE# is
    re-asserted.
    [buttons.c, main.c]
2018-09-10 Fixed issues with the STP08DP05 and SPI
    Apparently all signals are synchronous. This isn't immediately obvious
    from the datasheet, but the Table 9 does attempt to clearly show it.
    The various issues here were mainly fixed by enabling pulldowns (since
    the SPI Hi-Z's everything when disabled) and temporarily changing the
    SCLK I/O back to a regular output briefly to create an extra clock pulse
    when performing the latching operation.
    [buttons.c]
2018-09-14 Fixed issues with the read btns and write leds methods
    [buttons.c, main.c]
2018-09-15 Changed Midi logic to use a lossy ring buffer and ZLPs
    This should prevent stale data from being queued somewhat, so long as
    the device only sends data when necessary.
    [main.c]
2018-09-15 Added Midi send complete hook to facilitate periodic device updates.
    The plan is that if it has been a long-ish time since a packet has been
    sent to the host, then the device will send its entire state.
2018-09-15 Fixed a rather subtle mistake with the midi queue
    It wasn't properly asking if the queue was empty. It would only
    partially flush the queue and only rarely actually fully flush it.
    This caused buffers to be transmitted one after the other, which it
    turns out actually bogs down the processor significantly. Stuff would
    still respond, but very delayed.
    [main.c]
2018-09-15 Added storage abstraction to the configuration layer
    This should keep us from needing to put the storage.xml-based magic
    variable names everywhere. Instead, we can call functions which will
    read the storage for us.
    [configuration.h]
2018-09-19 Added initial mackie control emulation
    Surprisingly, it seems to work. The faders are a tad noisy, though.
    [configuration.h]
2018-09-19 Changed configurator to use names and fixed storage bug
    Just a tiny bug with reading the configuration, it wouldn't have
    affected the operation of the device.
2018-09-20 Added initial bootloader from the led-watch project, non-working
    [flash.cfg]
2018-09-26 Enabled debug, flashing, and updating using the bootloader
    I have no idea if this will actually work yet, but it does allow
    rudimentary bootloader debugging. I may have to add a special target for
    invoking gdb primarily with the bootloader.
    [flash.cfg]
2018-09-27 Changed bootloader dispatcher to use reserved RAM instead of the PC
    If an interrupt interrupted another one at just the right time it would
    see that it was inside the bootloader...and immediately jump to the
    bootloader code instead of the user app code. The reserved RAM approach
    is far simpler.
2018-09-27 Fixed the USB descriptor generator to handle the HID indexing
    I did not realize that the HID report index needed to be the index of
    the interface, but it makes sense. We had just so happened to always
    compile in just the right order so the index was zero, but with the
    bootloader addition that changed. For the bootloader, it is still
    interface 0, but for the device it is interface 2. The descriptorgen
    (which is already a horrible hack) was hacked further to support this.
    [main.c]
2018-09-29 Added initial bootloader python programmer script
    I needed to add an explicit erase command since the erase size and the
    program size are not the same on the STM32F0xx.
    I added the initial implementation of the midi-fader resetting into the
    bootloader, but I have not yet been successful in getting the actual
    firmware to run. There is a bug right now with the script where it can't
    handle dis-contiguous hex files for some reason.
    [configuration.h]
2018-09-29 Fixed the case where blocks are non-contiguous
    If the address of the new segment is after the address of the current
    segment, but still within the page, we get to pad.
2018-09-30 Fixed a bug with the hid endpoints, the bootloader now works
    There is still some unreliablility when aborting the bootloader and then
    changing the device back into bootloader mode. However, for development
    this is acceptable.
2018-12-22 Fixed USB descriptor string length problem
    [main.c]
2018-12-22 Fixed string lang descriptor to be proper length
    I still have problems with the device enumerating in linux, but maybe
    it's not a problem?
    [main.c]
2018-12-22 Updated storage to new defaults that fix pitch bend problems
2018-12-25 Changed debug trace for USB to be more verbose
2019-02-16 Downgraded USB version to avoid requesting the device qualifier
    There is most definitely a problem involving stalls, so the fewer
    planned stalls the better I think.
    [main.c]
2019-02-16 Expanded USB logging considerably so that every event is logged
    The result of this experiment is that there is definitely a problem with
    the control transfer state machine. It frequently stalls on transactions
    that should be considered valid.
2019-02-21 Fixed a bug in USB where a SETUP was causing a false OUT to be received
    I'm not convinced this is the end of the USB bugs (there's still
    a STALL every other configuration request which is not right). But,
    things now seem to enumerate reliably.
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2019-09-09 Started moving the device abstraction to be Evented
    I'm attempting to implemente asynchronous reads/writes.
2019-09-09 Changed device to use raw libc calls, started making futures
2019-09-09 Fixed reads/writes; futures now work
    [main.rs]
2019-09-09 Added the firmware status command
    [configuration.h]
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2019-09-09 Created configuration processor based on futures
    The GUI thread (which is the main thread) is going to use a tokio mpsc
    to send requests to this task which processes the requests as a stream.
    Each request gets its own tokio response queue which will be manually
    polled by the GUI thread until the result is complete.
2019-09-09 Changed out error_chain for failure
    Apparently error_chain is deprecated, but the real reason for this
    change is the fact that error_chain is !Send. The failure crate is far
    simpler and will be Send if the underlying types are Send.
    [main.rs]
2019-09-09 Completed state machine for finding the device and improved docs
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2019-09-09 Added error handling box that allows quit/continue functionality
    [main.rs]
